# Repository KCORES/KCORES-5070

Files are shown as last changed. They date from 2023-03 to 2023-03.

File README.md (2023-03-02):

# DELL Wyse 5070 Hacking

关于 DELL Wyse 5070 主板的一些硬件分析和逆向工程

- 介绍视频：[省到离谱，比树莓派还省电的x86主板](https://youtu.be/9opQ4gsh4Hg)

- 交流QQ群：[655944532](https://jq.qq.com/?_wv=1027&k=KV0wy6gJ)

## 主要贡献者

- [@Havoc](https://github.com/Wangrb)
- [@Naivekun](https://github.com/naivekun)
- [@AlphaArea](https://github.com/alphaarea)

## Wyse 5070 基本介绍

Wyse 5070 分为胖瘦两种机型, 主要区别如下

| 瘦机 | 胖机 |
| --- | --- |
| PCIe 插槽空焊 | 有 PCIe 插槽 |
| 无风扇 | 有风扇 |
| 检测 90W 电源 | 检测 120W 电源 |

注: 不同批次的主板, 元器件型号可能存在区别

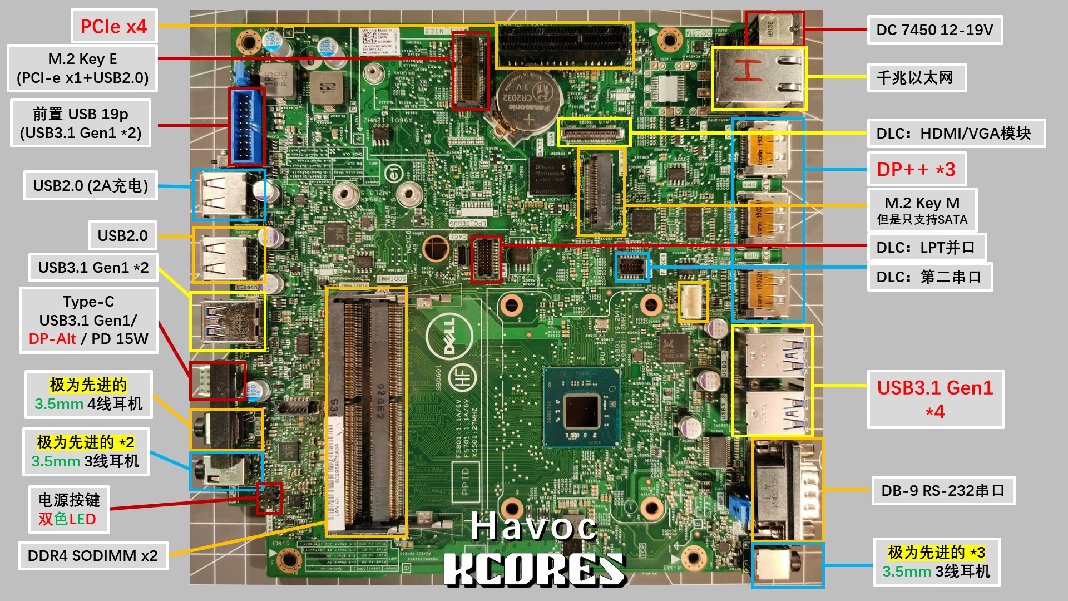
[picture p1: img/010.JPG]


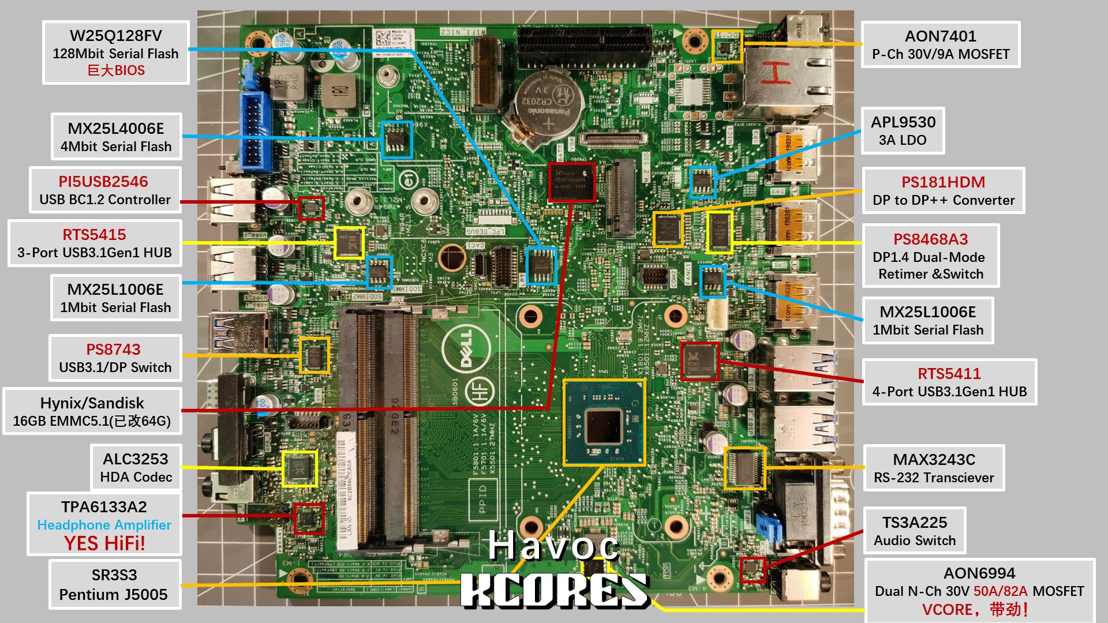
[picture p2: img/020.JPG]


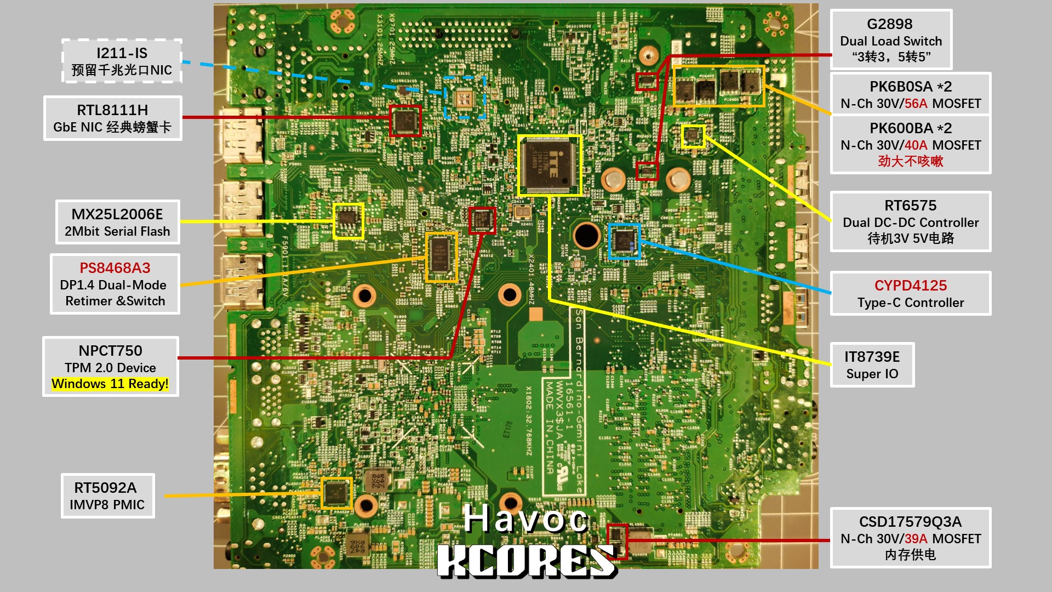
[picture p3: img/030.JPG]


## 刷 BIOS

BIOS 文件在 BIOS 文件夹中, 刷入可以直接解决电源识别问题并提升性能, 但是 DELL 的保护不允许软刷入 BIOS, 必须使用 CH341A 编程器直接刷入 BIOS 芯片.

BIOS 文件由 [@Naivekun](https://github.com/naivekun) 修改, 主要功能:

- 删除电源功率检测, 只要插上电就能用
- 提高 PL1 睿频限制, 性能看齐 J5040
- 提高 CPU 主频 (未生效)

⚠注意: 刷入 BIOS 可能导致主板序列号和集成网卡 MAC 地址改变

## 电源

### 电压范围

实测 Wyse5070 允许 9~20V 范围的宽电压供电, 如果使用电池可以 4S 锂电池直通, 免去稳压提高电池利用率

### 电源识别

建议使用 DELL 供电转接头, 并且最好买标明已刷入 120W 信息的型号, 免得插到胖机主板上识别为供电不足禁止睿频

不建议使用原装 19V 笔记本电源, 因为后续使用 PCIe 转接卡需要 12V 供电

## 开机排线

开机排线必须连接检测针, 否则开机必跳警告

插座型号: 2.0mm 排针

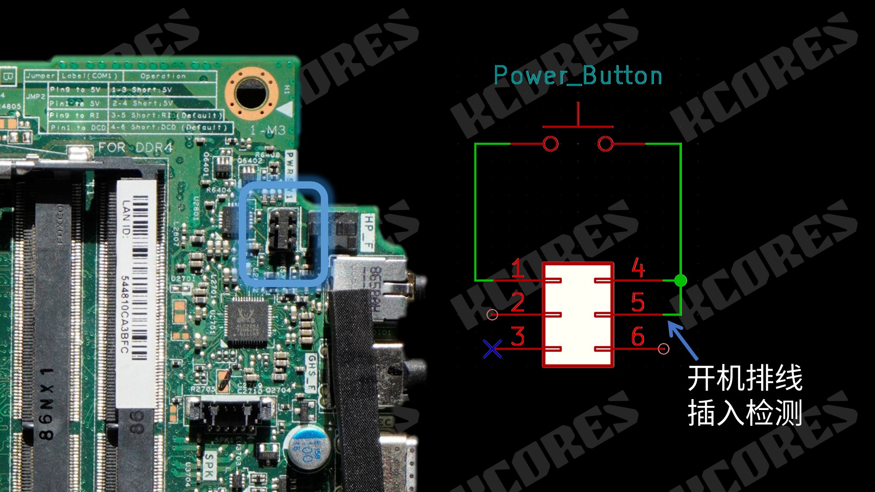
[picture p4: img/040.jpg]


## 喇叭排线

如果不使用声卡也不使用板载喇叭, 可以不管

插座型号: SH1.25

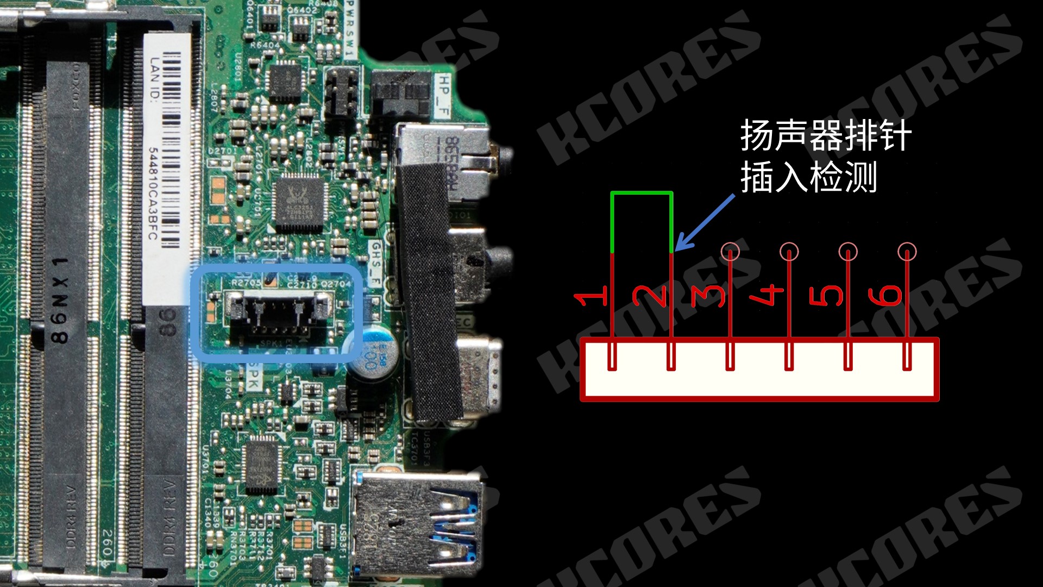
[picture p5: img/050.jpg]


## eMMC

理论上 eMMC 是标准接口全兼容, 但实际上 intel 的 eMMC 一直存在玄学兼容问题, 如需自行安装或扩容建议选择原装同系列的 eMMC

- SKhynix H26M51002KPR
- SanDisk SDINADF4-16G

## PCIe

**⚠警告: 使用 DIY PCIe 转接板必须搭配 12V DC 电源, 使用 19V 笔记本电源将烧毁 PCIe 设备**

1. 胖机可以直接使用转接卡插上 PCIe 设备使用

2. 除非有电动吸锡器等专业工具, 否则不建议用普通装备挑战 DELL 的多层 PCB 过孔灌锡, 很可能彻底损坏 PCIe 插槽焊盘

3. 时钟请求电路见下图  
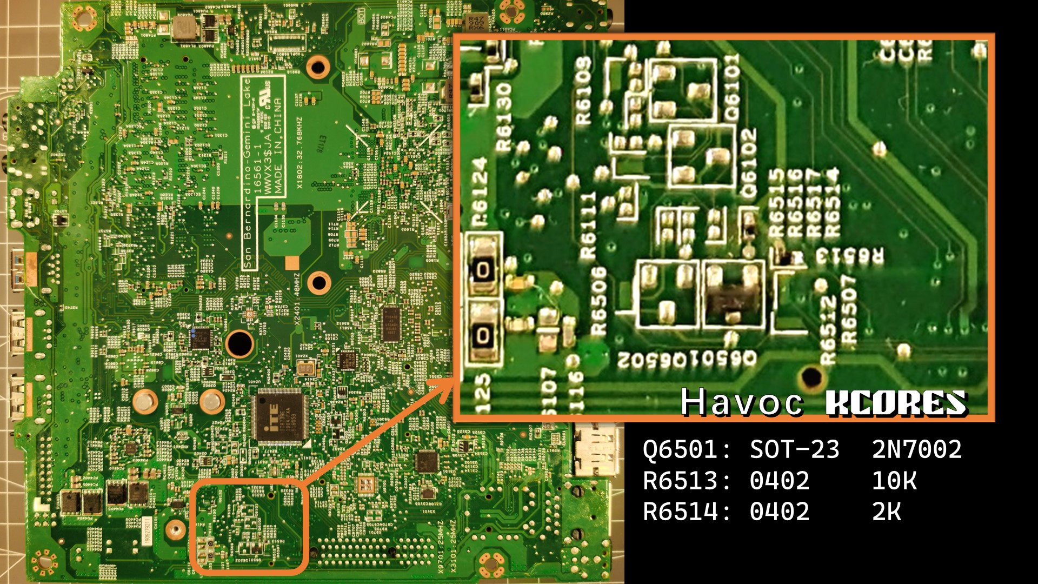
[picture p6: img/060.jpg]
  

4. 转接卡图纸见 pcie 文件夹, 使用 KiCAD 编辑. 转接板尺寸为自制亚克力外壳设计, 不兼容原厂机箱.

## 散热片

散热片模型见 heatsink 文件夹

## 亚克力外壳

亚克力文件见 case 文件夹

- 上板与主板固定使用 M3x14mm 铜柱
- 下板与主板固定使用 M3x6mm 铜柱

该尺寸为自制 PCIe 转接板设计, 不兼容原厂 PCIe 扩展板

## 开机注意事项

Wyse 5070 的开机逻辑和常见 DIY 主板不同, 它的自检发生在更换硬件后的第一次上电时(无论是否按下开机按钮). 

建议使用可显示电流的稳压电源测试, 自检持续数十秒后电流会降低到 0.1A 以下, 此时自检完成可以按电源键开机.

若自检持续一分钟以上, 且电流不波动, 一般是内存没有装好.

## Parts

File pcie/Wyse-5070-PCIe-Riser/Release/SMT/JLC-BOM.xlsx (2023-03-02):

Comment | Designator | Footprint
100nF | C6,C4,C1,C7,C3,C5,C8,C2 | 0402

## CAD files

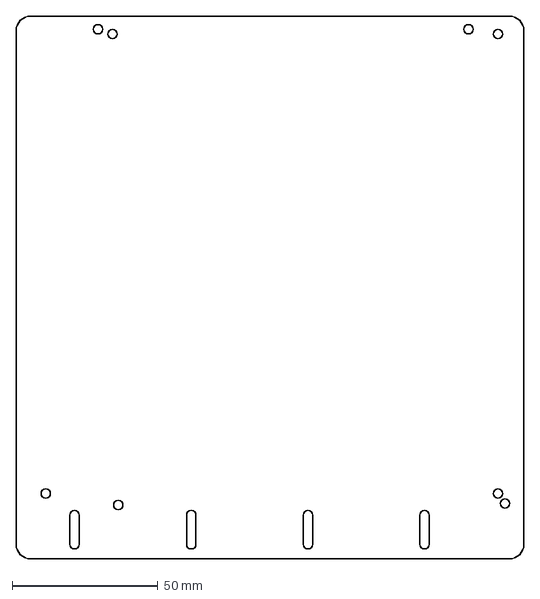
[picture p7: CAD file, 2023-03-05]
case/Wyse5070Board.DXF
174.0 x 186.0 mm

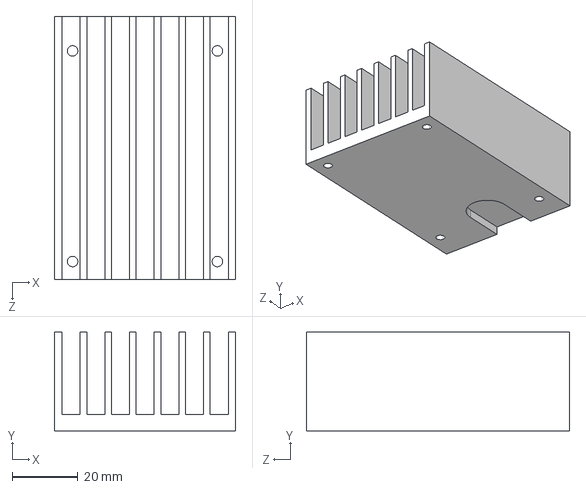
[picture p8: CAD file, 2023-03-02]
heatsink/Wyse5070HeatSink-Hole.STEP
55.0 x 30.0 x 80.0 mm

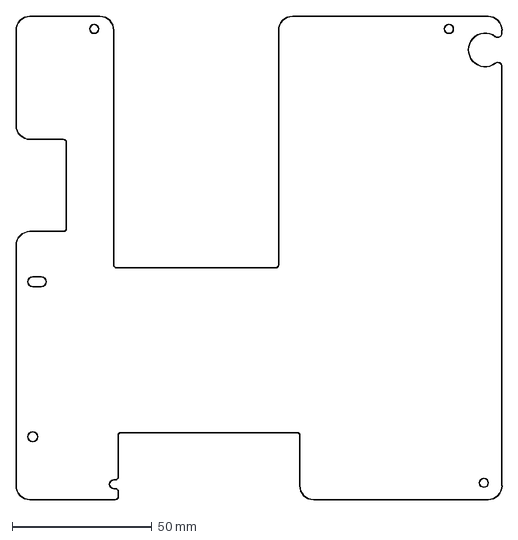
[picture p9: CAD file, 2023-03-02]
case/Wyse5070Cover-V2.DXF
174.0 x 173.0 mm

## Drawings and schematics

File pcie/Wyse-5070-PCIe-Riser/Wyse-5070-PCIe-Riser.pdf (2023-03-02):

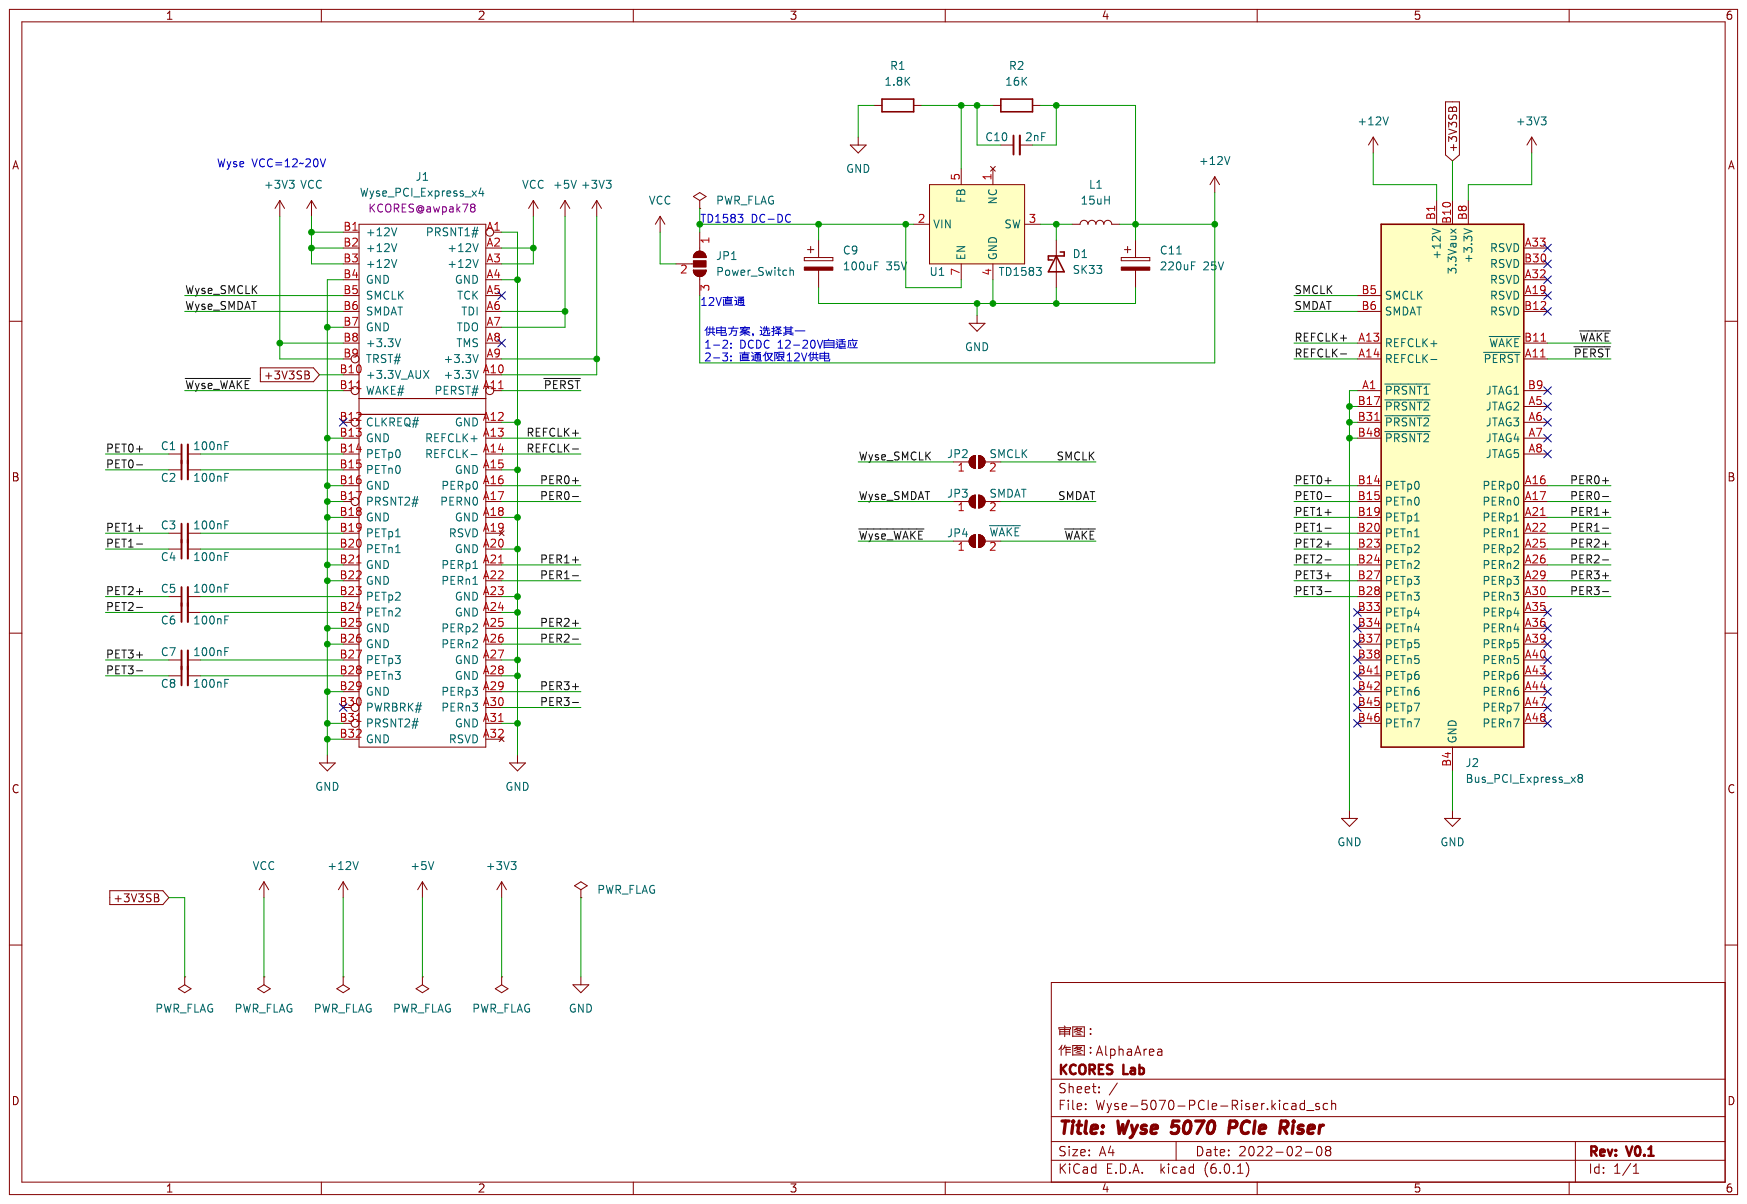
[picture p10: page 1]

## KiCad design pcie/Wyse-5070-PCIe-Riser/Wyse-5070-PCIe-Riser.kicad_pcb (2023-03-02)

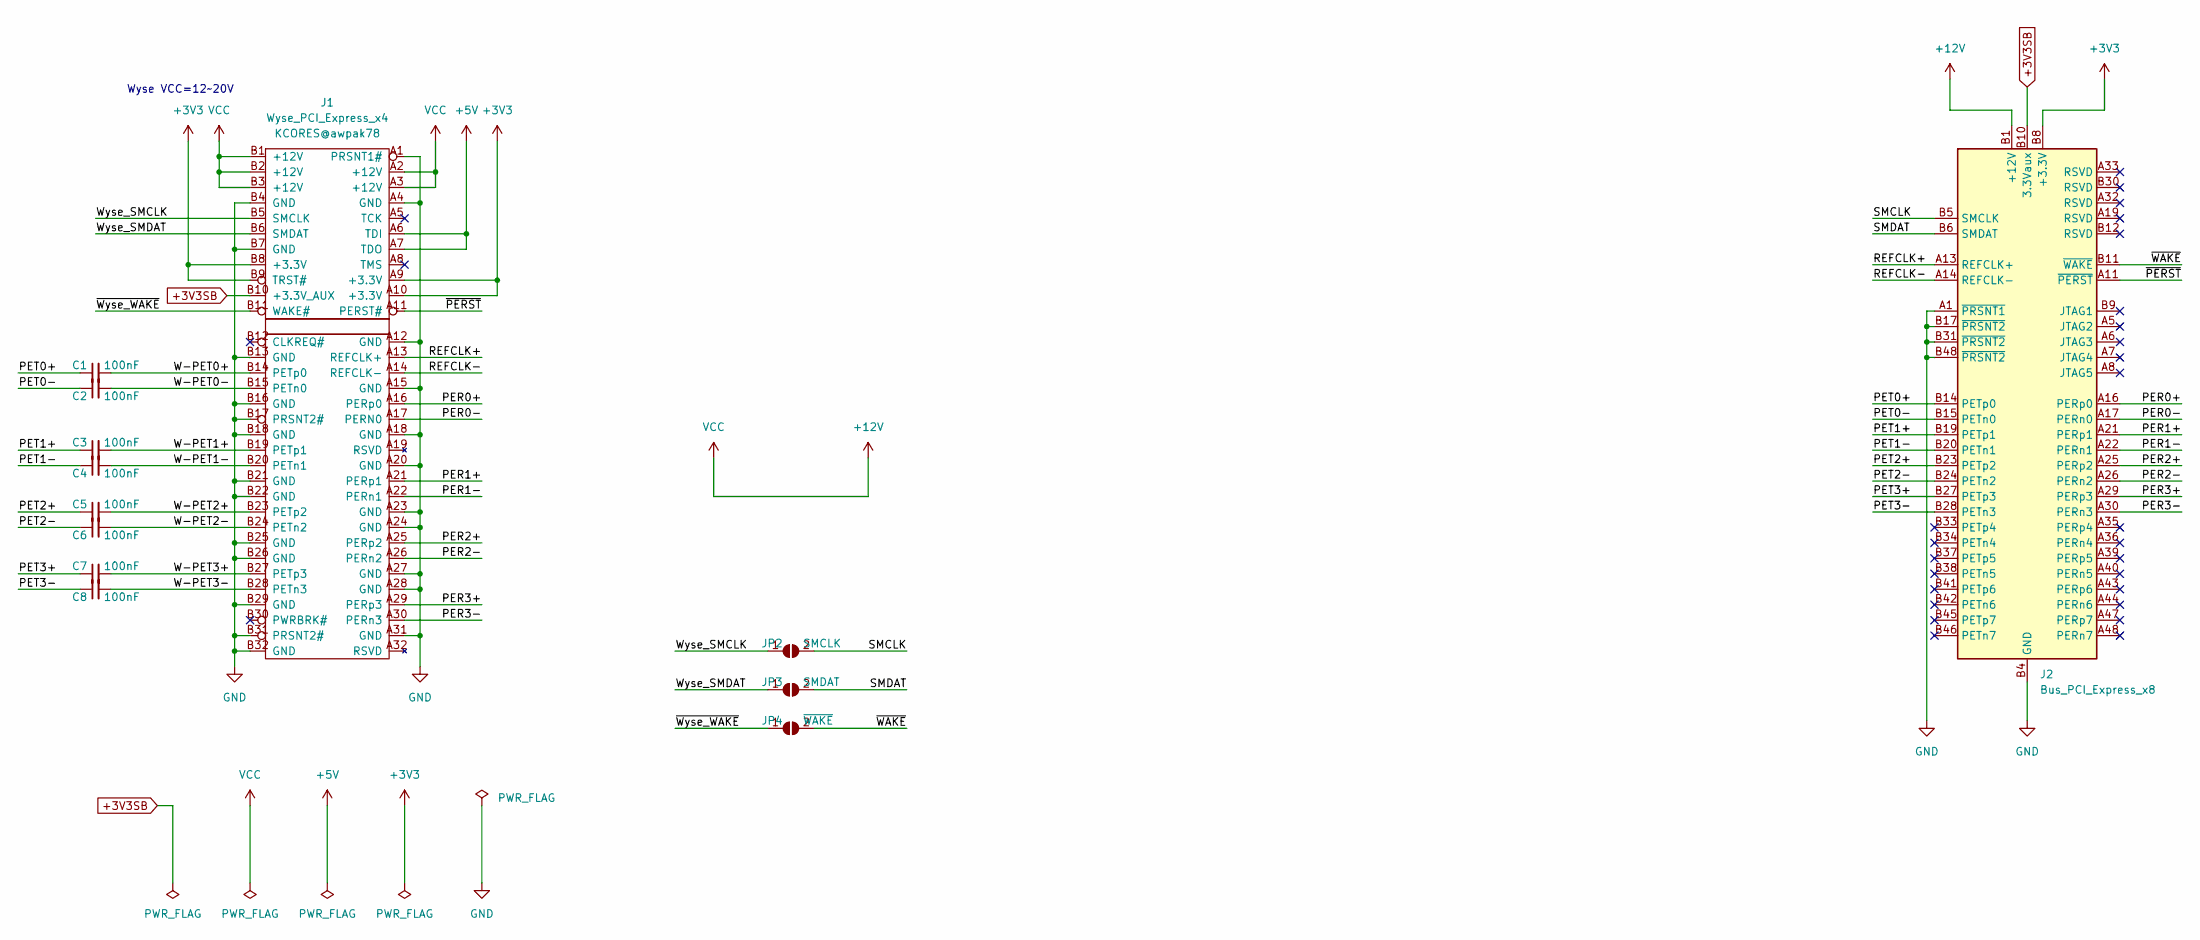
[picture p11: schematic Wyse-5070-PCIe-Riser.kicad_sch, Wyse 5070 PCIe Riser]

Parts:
C1, C2, C3, C4, C5, C6, C7, C8: 100nF; C_0402_1005Metric
J1: Wyse_PCI_Express_x4; BUS_PCIexpress_x4
J2: Bus_PCI_Express_x8; PCIe_Vertical_SMT_x8
JP2: SMCLK; SolderJumper-2_P1.3mm_Open_RoundedPad1.0x1.5mm
JP3: SMDAT; SolderJumper-2_P1.3mm_Open_RoundedPad1.0x1.5mm
JP4: ~{WAKE}; SolderJumper-2_P1.3mm_Open_RoundedPad1.0x1.5mm

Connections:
+3V3: J1.A9 (+3.3V), J1.A10 (+3.3V), J1.B8 (+3.3V), J1.B9 (TRST#), J2.A9 (+3.3V), J2.A10 (+3.3V), J2.B8 (+3.3V)
+3V3SB: J1.B10 (+3.3V_AUX), J2.B10 (3.3Vaux)
+5V: J1.A6 (TDI), J1.A7 (TDO)
+12V: J1.A2 (+12V), J1.A3 (+12V), J1.B1 (+12V), J1.B2 (+12V), J1.B3 (+12V), J2.A2 (+12V), J2.A3 (+12V), J2.B1 (+12V), J2.B2 (+12V), J2.B3 (+12V)
/PER0+: J1.A16 (PERp0), J2.A16 (PERp0)
/PER0-: J1.A17 (PERN0), J2.A17 (PERn0)
/PER1+: J1.A21 (PERp1), J2.A21 (PERp1)
/PER1-: J1.A22 (PERn1), J2.A22 (PERn1)
/PER2+: J1.A25 (PERp2), J2.A25 (PERp2)
/PER2-: J1.A26 (PERn2), J2.A26 (PERn2)
/PER3+: J1.A29 (PERp3), J2.A29 (PERp3)
/PER3-: J1.A30 (PERn3), J2.A30 (PERn3)
/PET0+: C1.1, J2.B14 (PETp0)
/PET0-: C2.1, J2.B15 (PETn0)
/PET1+: C3.1, J2.B19 (PETp1)
/PET1-: C4.1, J2.B20 (PETn1)
/PET2+: C5.1, J2.B23 (PETp2)
/PET2-: C6.1, J2.B24 (PETn2)
/PET3+: C7.1, J2.B27 (PETp3)
/PET3-: C8.1, J2.B28 (PETn3)
/REFCLK+: J1.A13 (REFCLK+), J2.A13 (REFCLK+)
/REFCLK-: J1.A14 (REFCLK-), J2.A14 (REFCLK-)
/SMCLK: J2.B5 (SMCLK), JP2.2 (B)
/SMDAT: J2.B6 (SMDAT), JP3.2 (B)
/W-PET0+: C1.2, J1.B14 (PETp0)
/W-PET0-: C2.2, J1.B15 (PETn0)
/W-PET1+: C3.2, J1.B19 (PETp1)
/W-PET1-: C4.2, J1.B20 (PETn1)
/W-PET2+: C5.2, J1.B23 (PETp2)
/W-PET2-: C6.2, J1.B24 (PETn2)
/W-PET3+: C7.2, J1.B27 (PETp3)
/W-PET3-: C8.2, J1.B28 (PETn3)
/Wyse_SMCLK: J1.B5 (SMCLK), JP2.1 (A)
/Wyse_SMDAT: J1.B6 (SMDAT), JP3.1 (A)
/~PERST: J1.A11 (PERST#), J2.A11 (~PERST)
/~WAKE: J2.B11 (~WAKE), JP4.2 (B)
/~Wyse_WAKE: J1.B11 (WAKE#), JP4.1 (A)
GND: J1.A1 (PRSNT1#), J1.A4 (GND), J1.A12 (GND), J1.A15 (GND), J1.A18 (GND), J1.A20 (GND), J1.A23 (GND), J1.A24 (GND), J1.A27 (GND), J1.A28 (GND), J1.A31 (GND), J1.B4 (GND), J1.B7 (GND), J1.B13 (GND), J1.B16 (GND), J1.B17 (PRSNT2#), J1.B18 (GND), J1.B21 (GND), J1.B22 (GND), J1.B25 (GND), J1.B26 (GND), J1.B29 (GND), J1.B31 (PRSNT2#), J1.B32 (GND), J2.A1 (~PRSNT1), J2.A4 (GND), J2.A12 (GND), J2.A15 (GND), J2.A18 (GND), J2.A20 (GND), J2.A23 (GND), J2.A24 (GND), J2.A27 (GND), J2.A28 (GND), J2.A31 (GND), J2.A34 (GND), J2.A37 (GND), J2.A38 (GND), J2.A41 (GND), J2.A42 (GND), J2.A45 (GND), J2.A46 (GND), J2.A49 (GND), J2.B4 (GND), J2.B7 (GND), J2.B13 (GND), J2.B16 (GND), J2.B17 (~PRSNT2), J2.B18 (GND), J2.B21 (GND), J2.B22 (GND), J2.B25 (GND), J2.B26 (GND), J2.B29 (GND), J2.B31 (~PRSNT2), J2.B32 (GND), J2.B35 (GND), J2.B36 (GND), J2.B39 (GND), J2.B40 (GND), J2.B43 (GND), J2.B44 (GND), J2.B47 (GND), J2.B48 (~PRSNT2), J2.B49 (GND)

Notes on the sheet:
Wyse VCC=12~20V

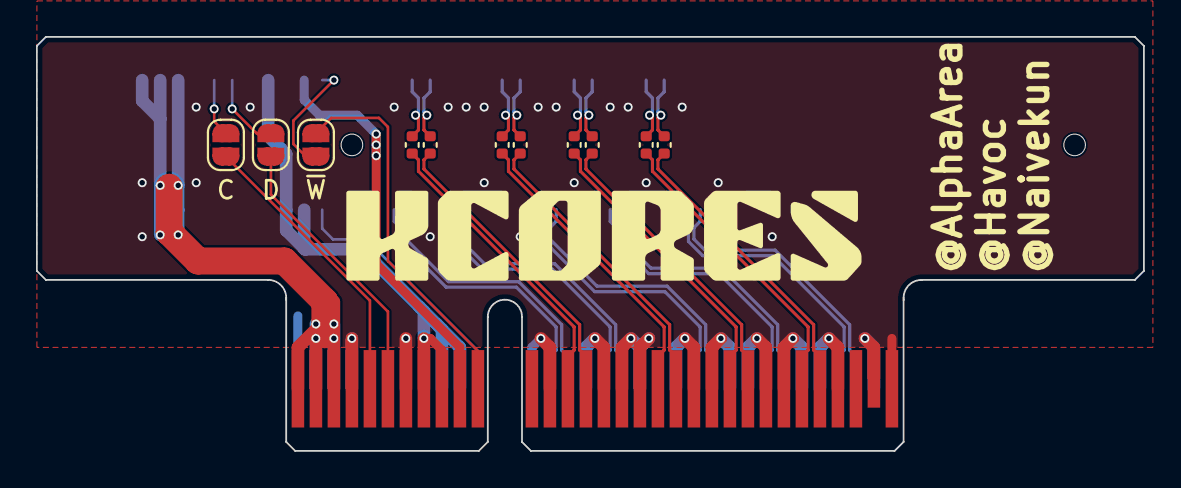
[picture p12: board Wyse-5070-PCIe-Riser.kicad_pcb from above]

Board: 2 copper layers, 61.5 x 23.0 mm, 13 parts (1 on the bottom side), 38 nets.

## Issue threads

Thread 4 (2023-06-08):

5070 瘦机刷入魔改 BIOS 无法开机

xddxdd, 2023-06-08:
机器 CPU 是 J5005，原机 BIOS 版本 1.8.0。

用编程器刷入 bios 文件夹中的魔改 BIOS 后无法开机，症状表现为电源灯白灯常亮，显示器无信号。刷回原机 BIOS 备份后可以正常开机。

以下是我的 BIOS 备份以供参考：[wyse5070backup.zip](https://github.com/KCORES/KCORES-5070/files/11684176/wyse5070backup.zip)

liujiaxian, 2023-06-16:
能分享一下用编程器刷bios主板怎么接线吗？

alphaarea, 2024-04-06:
1. 检查下载的 BIOS 文件是否完整, 刷入魔改 BIOS 无法开机的常见原因是文件不完整
2. 无法确定所有的 Wyse5070 BIOS 都可以通用, 如果实在没办法只能用你原装的 BIOS

Maotechh, 2025-02-24:
同样J5005.同样刷了无法开机

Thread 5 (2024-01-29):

PCIE转接板的问题

NoopLoop00, 2024-01-29:
关于供电方案有个问题，我看原理图标注1-2是自适应电压，是不是把3脚悬空就可以了？还需要配合电路改造吗

alphaarea, 2024-04-06:
供电方案没什么可改的, 用 PCIe 就配 12V 电源.

转接卡上加一个能跑 5A 的 19V - 12V 降压电路随便就是一二十块钱出去了

Closed 2024-04-06.

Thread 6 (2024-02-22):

Remove restriction on A+E key devices?

justinj57, 2024-02-22:
Is it possible to add the ability to use an a+e key m.2 to PCI-e adapter?  As of right now, Dell appears to restrict this slot for only approved devices (Dell secondary NIC modules)

alphaarea, 2024-04-06:
What specific device are you having trouble on M.2?

In my experience, other brand M.2 NIC work fine.

justinj57, 2024-04-06:
I cannot get either of my two slim 5070s to recognize anything on my m.2
a+e key to pci-e adapter (I've tried 2), except a single port i210 nic.  I
have tried multiple i340 and i350 cards (2 and 4 port, with and without
external 12v) and I get nothing

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

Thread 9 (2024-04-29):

Schematics and BoardView

raenye, 2024-04-29:
Could you please upload schematics and/or boardview file for the 5070? thanks :)

alphaarea, 2024-05-03:
This is just reverse engineering, not breaking into the DELL R&D center!

Closed 2024-05-03.

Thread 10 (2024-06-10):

主板前置 19 pin 提供的应该是 USB 3.0+USB 2.0

Icarusradio, 2024-06-10:
翻看 DELL 自己的文档以及他人折腾的记录可以发现前置的 19 pin 提供的应该是一个 USB 3.0 和一个 USB 2.0
https://www.dell.com/support/manuals/en-us/wyse-5070-thin-client/5070_std_ug/welcome-to-dell-wyse-5070-thin-client
https://www.parkytowers.me.uk/thin/wyse/5070/
我自己测试下来也是这个结果

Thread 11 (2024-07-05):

请问J4105的机型可以刷代码库中的BIOS吗？

kqkq, 2024-07-05:

alphaarea, 2024-07-08:
没有测试过, 请自备编程器随时准备救砖

komadinaa, 2024-07-16:
Hi ,, i tested bios from this source, but it seems that it wont boot. When i flash back old bios everything works fine .
is tehere anybody who sucssesfuly flashed bios  ? maybe its bios problem?

Maotechh, 2025-02-24:
> Hi ,, i tested bios from this source, but it seems that it wont boot. When i flash back old bios everything works fine . is there anybody who successfully flashed this bios? maybe its bios problem?
>
> UPDATE: my dell wyse 5070 runs Celeron J4105 processor not J5005 .. can that be roblem of unsuccessful flashing? i can send copy of my bios , so if anyone knows how to make modification for this spceciffic cpu it would be nice. (if cpu can be the case ) many thanks

Same issue. But my device is J5005. I can't boot after flashing the bios file in this repo, either.

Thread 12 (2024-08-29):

PCI MOD

komadinaa, 2024-08-29:
Hi.. just to give some report about this mod..

I followed guide from this website  ( I was unable to open all files but I figured out what is needed to be soldered on motherboard)

I did modification but without success about stepping down voltage.. everything is placed as explained and Maschine boots.

2 resistors and one relay .. but voltage on PCI slot is still 20 v ( adapter is 20 v)
It gave me idea to pull out PCI pins that conduct power and add ,,voltage step Buck '' in between to lower voltage to 12 v. (But I believe that this will take a lot of time )

I also have to report that I found none of points, that shows me 12 v on voltmeter
So I am not sure if that voltage even exists on this slim motherboard because none of components use 12 v to operate. Voltage on board is mostly about 1.4v 3.3v; 5.1v

Maybe something else is needed to be added on board but as I said I was not able to open all files.

Any suggestion is welcome since the internet is full of this discussion but I haven't seen no one that presented full sucsses.
what I think that I missed is ,, MWSA0603`` since its mentioned in files

Many thanks

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

DanielStones, 2024-10-04:
See readme PCIe section
⚠警告: 使用 DIY PCIe 转接板必须搭配 12V DC 电源, 使用 19V 笔记本电源将烧毁 PCIe 设备
Google translate
Warning: The DIY PCIe adapter board must be used with a 12V DC power supply. Using a 19V laptop power supply will burn the PCIe device.
It's advise to use a riser to connect pcie devices, because lack of decoupling capacitor on the main board
also see #5 use Google translate

komadinaa, 2024-10-10:
Hi.. many thanks for your response . Maybe I misunderstand google translate ( I was thinking that PCB modification will make effect on voltage and drop woltage to 12v on needed point) but it's clear now . 12v power is ,,must'' to make this work and proper PCB soldering.
#5 - this discussion helped me a lot.
